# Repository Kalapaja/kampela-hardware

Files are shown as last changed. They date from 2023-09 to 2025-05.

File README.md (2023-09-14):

# Kampela

## Reasonably secure hardware signer for the [Polkadot](https://polkadot.network) ecosystem

### Hardware design schematics and supplementary files

##### Note on repo history

This repo has been extracted from https://github.com/Alzymologist/kampela in September 2023 as a part of the repo modularization effort.

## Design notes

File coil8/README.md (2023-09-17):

# Kampela coil PCB

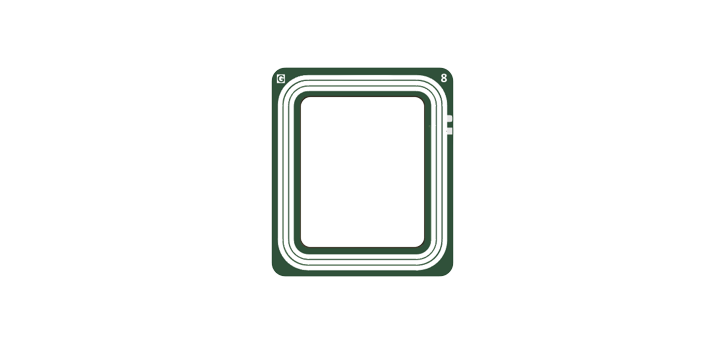
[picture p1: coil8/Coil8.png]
Kampela coil PCB


We are using a separate coil PCB to put it as much closer to the smartphone antenna as possible. 
8 turns design shows better energy performance for harvesting energy for Kampela.

The coil PCB connects with the main PCB with 2 short copper wires.

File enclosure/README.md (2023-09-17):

# Kampela Enclosure G2

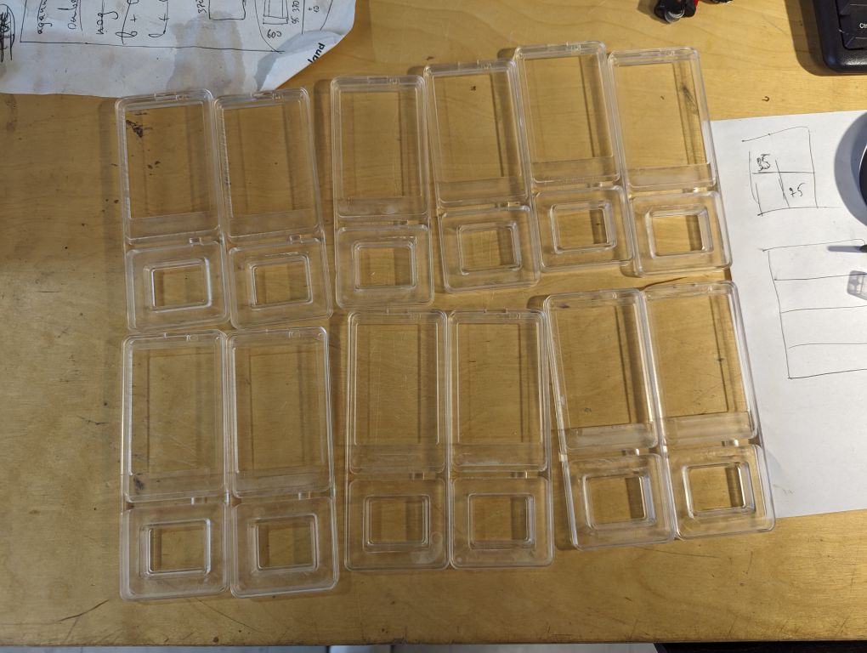
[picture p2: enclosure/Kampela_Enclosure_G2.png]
Kampela Enclosure G2


For the Kampela G2 revision, we use a rigid transparent acrylic enclosure made on a CNC machine from an 8mm transparent acrylic sheet and pour it with 2 components of transparent polyurethane after full assembly and testing.

For devkits (green PCBs and full transparent) there is an 8pin connector on the bottom of the device to connect it to the Pilkki flash tool.

Under the screen, there is a place for an NFC tag working in pair with Kampela.

Before placing the PCBs and the screen - you should put a flexible glue contour to all holes contours and glue all the components during assembly. This glue prevents polyurethane pouring from leaking on the screen and inside the devkit connector.

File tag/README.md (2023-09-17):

# Kampela NFC Tag

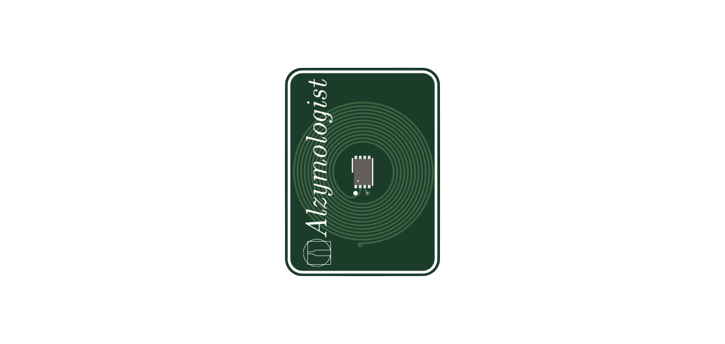
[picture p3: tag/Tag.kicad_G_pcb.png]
Kampela NFC Tag


Kampela NFC Tag is used as a Kampela companion for direct NFC communication with a phone, while Kampela remains be completely passive device minimizing the transmittion of any RF signal even not changing the NFC receiver quality factor to communicate with a user smartphone.

A nice bonus of this approach is that the tag is the second security factor - Kampela doesn't work without the correct tag to prevent simple attacks.

Kampela NFC Tag is also poured into a transparent enclosure to protect it from the harsh environment and silent modification.

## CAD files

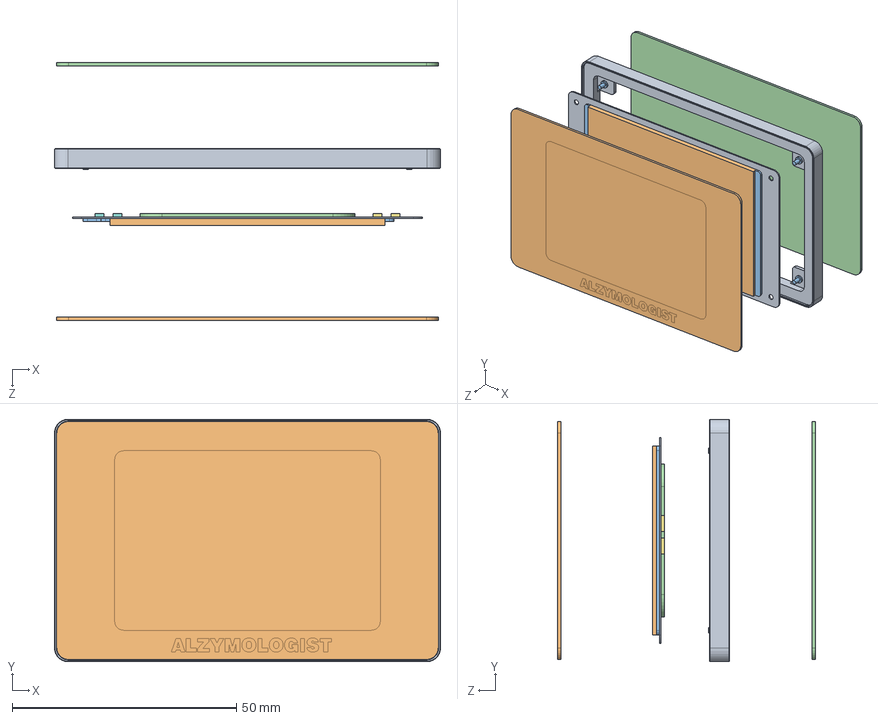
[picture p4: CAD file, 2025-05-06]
enclosure/new_layout/Assembly1.SLDASM
86.0 x 54.0 x 57.4 mm
плата
экран
обвязка экрана
нфц
детали 1
детали 2
детали 3
детали 4
Стекло front
Крепеж
Стекло

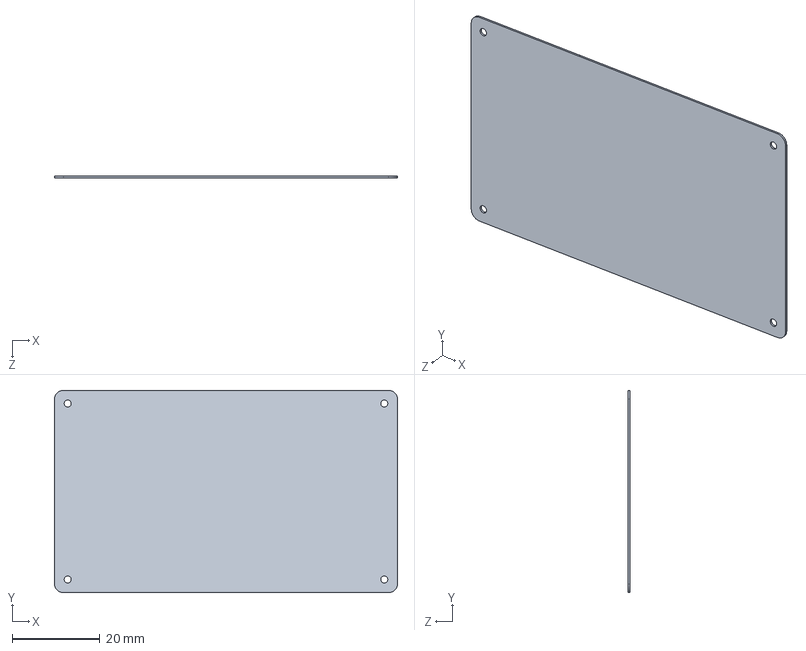
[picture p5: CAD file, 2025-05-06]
enclosure/new_layout/Board.SLDPRT
78.0 x 46.0 x 0.4 mm

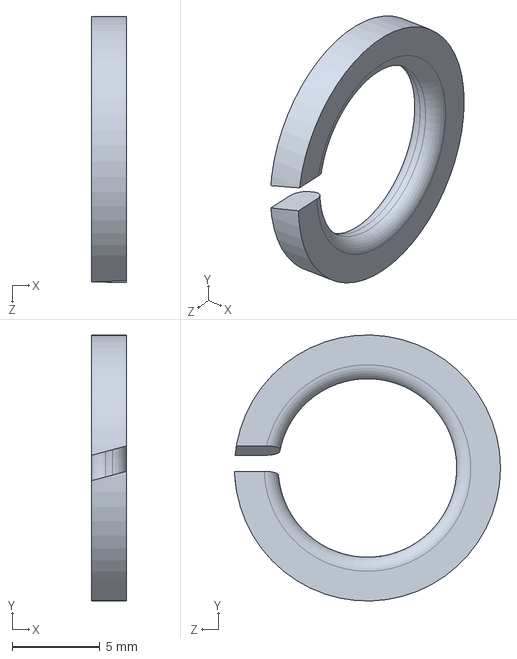
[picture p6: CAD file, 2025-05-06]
enclosure/new_layout/mass_production/PS-10.2x2.sldprt
2.00 x 15.2 x 15.2 mm

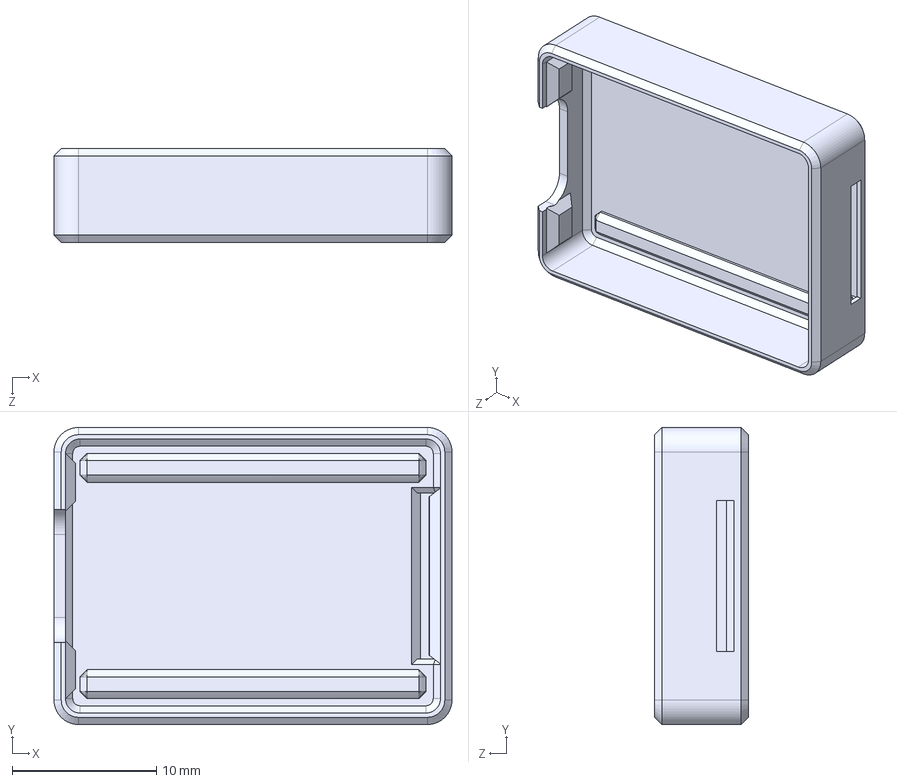
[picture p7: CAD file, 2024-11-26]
enclosure/Prog2Bot.STEP
27.6 x 20.6 x 6.50 mm

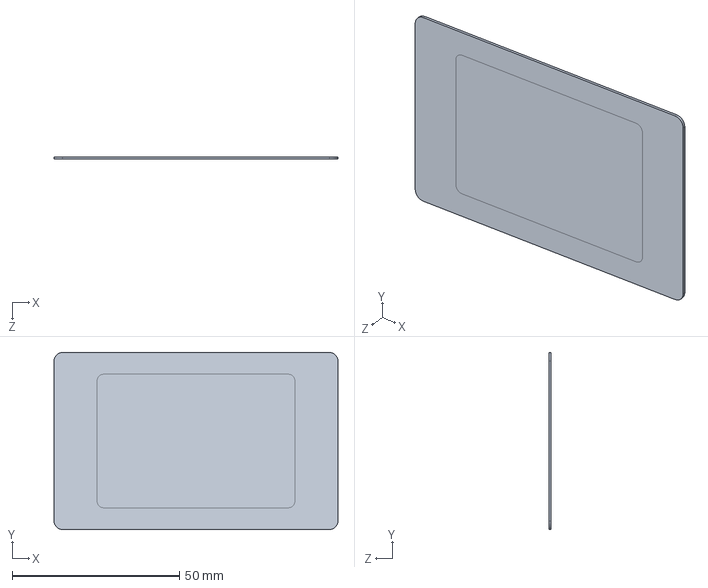
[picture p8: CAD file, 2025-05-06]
enclosure/new_layout/Glass front.SLDPRT
85.0 x 53.0 x 0.701 mm

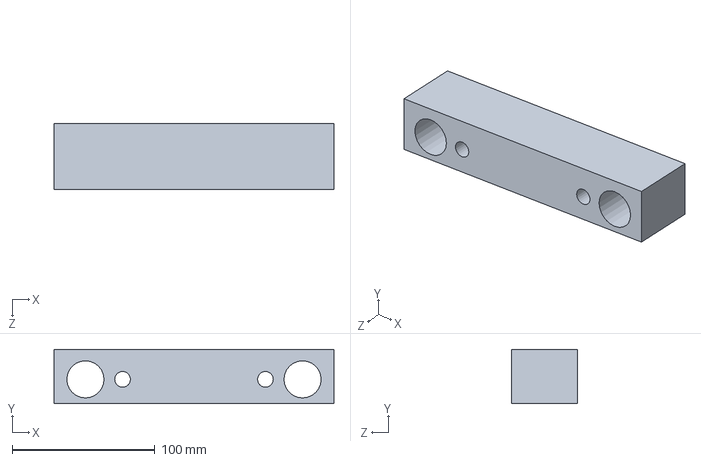
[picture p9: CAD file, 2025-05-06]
enclosure/new_layout/mass_production/PK 05-196x196x46_1730.sldprt
196.0 x 38.0 x 46.0 mm

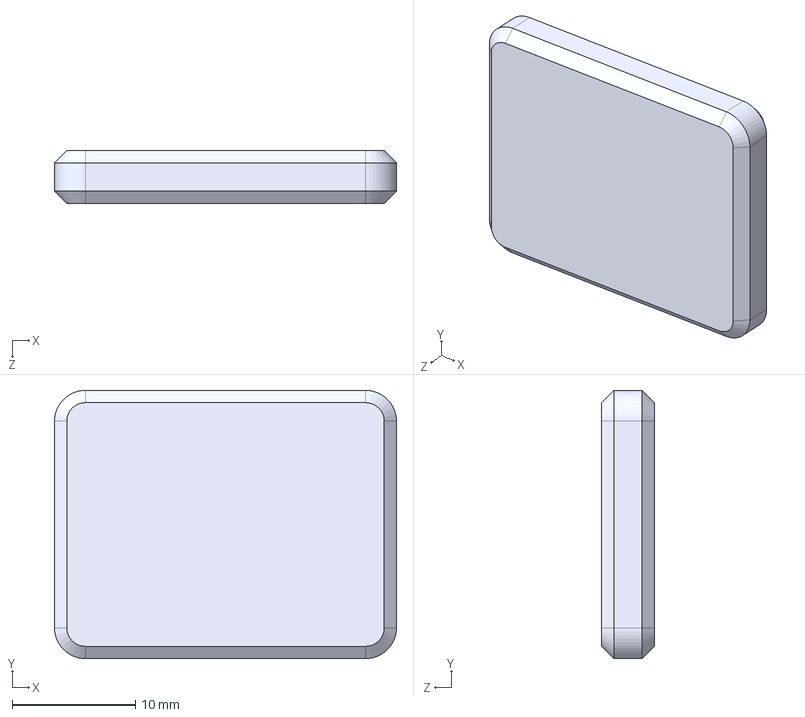
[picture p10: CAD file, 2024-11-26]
enclosure/TAG5.STEP
27.8 x 21.8 x 4.30 mm

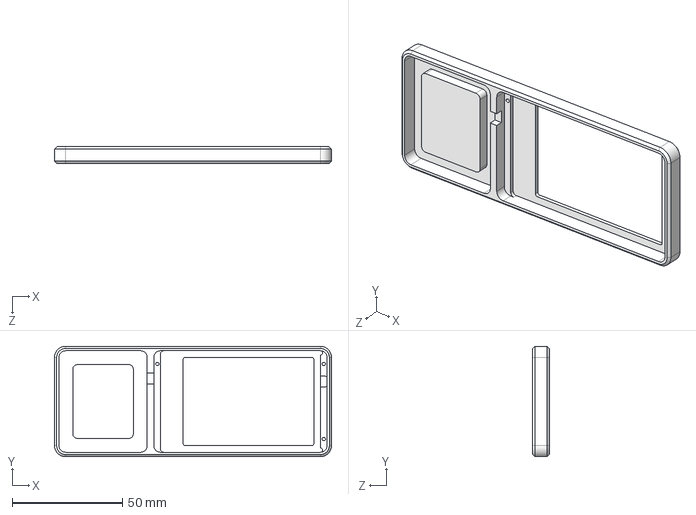
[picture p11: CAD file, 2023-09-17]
enclosure/Kampela_Enclosure.STEP
125.5 x 50.0 x 7.50 mm

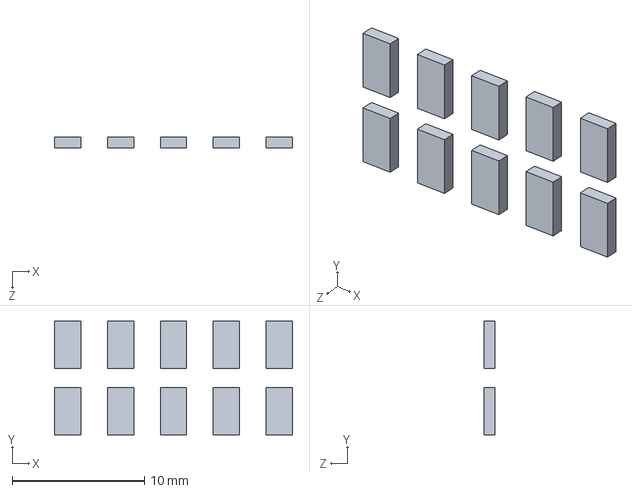
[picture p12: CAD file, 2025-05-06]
enclosure/new_layout/Details 1.SLDPRT
18.0 x 8.60 x 0.8 mm

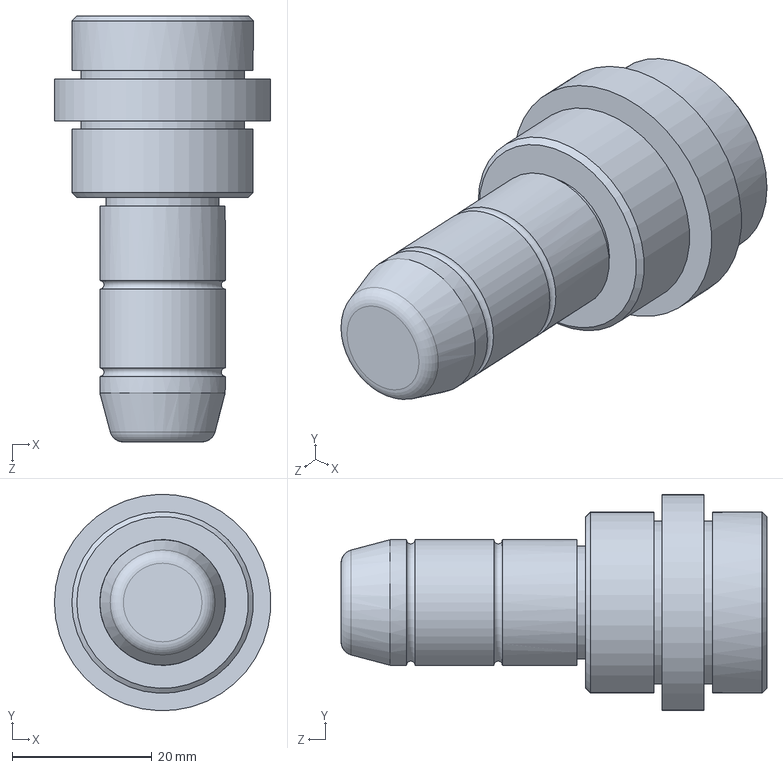
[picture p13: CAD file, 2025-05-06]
enclosure/new_layout/mass_production/SLE-18017035.sldprt
31.0 x 31.0 x 61.0 mm

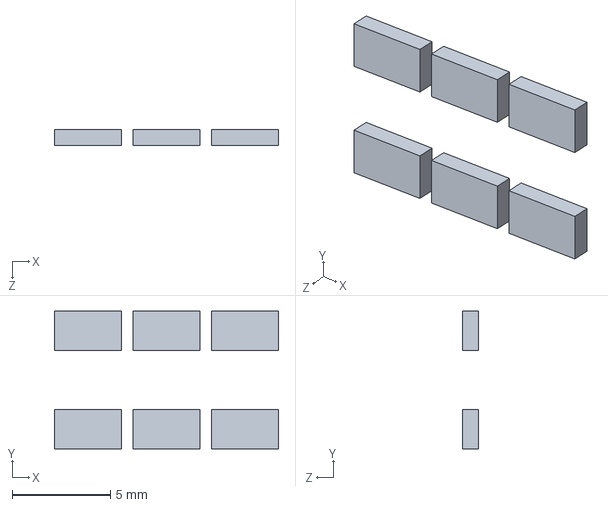
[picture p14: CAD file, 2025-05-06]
enclosure/new_layout/Details 2.SLDPRT
11.4 x 7.00 x 0.8 mm

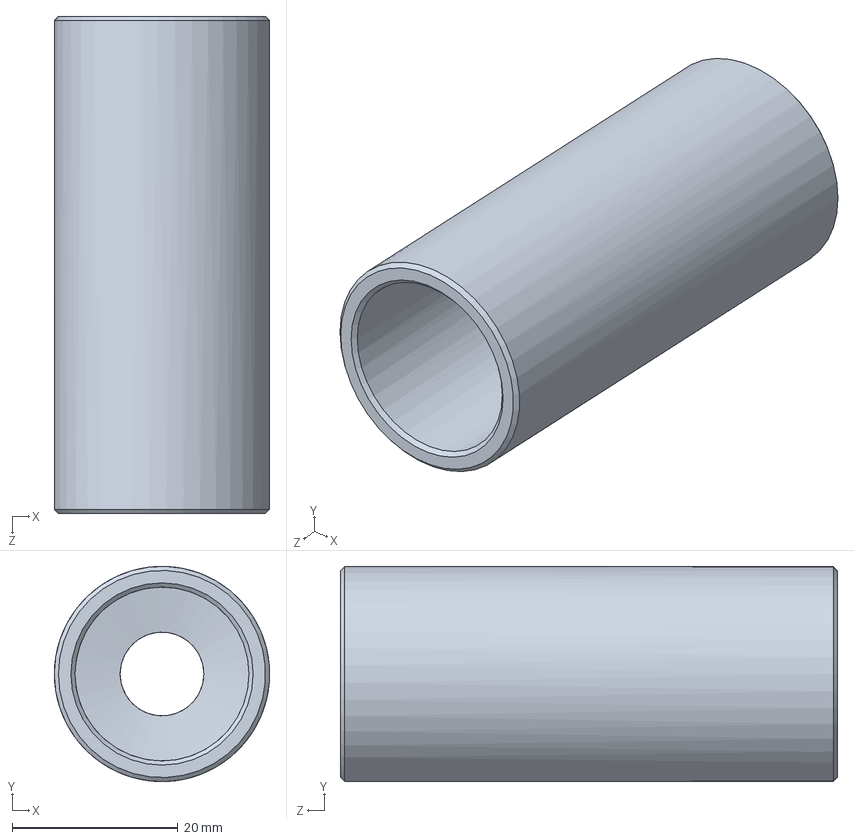
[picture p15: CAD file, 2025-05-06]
enclosure/new_layout/mass_production/TUE-26060.sldprt
26.0 x 26.0 x 60.0 mm

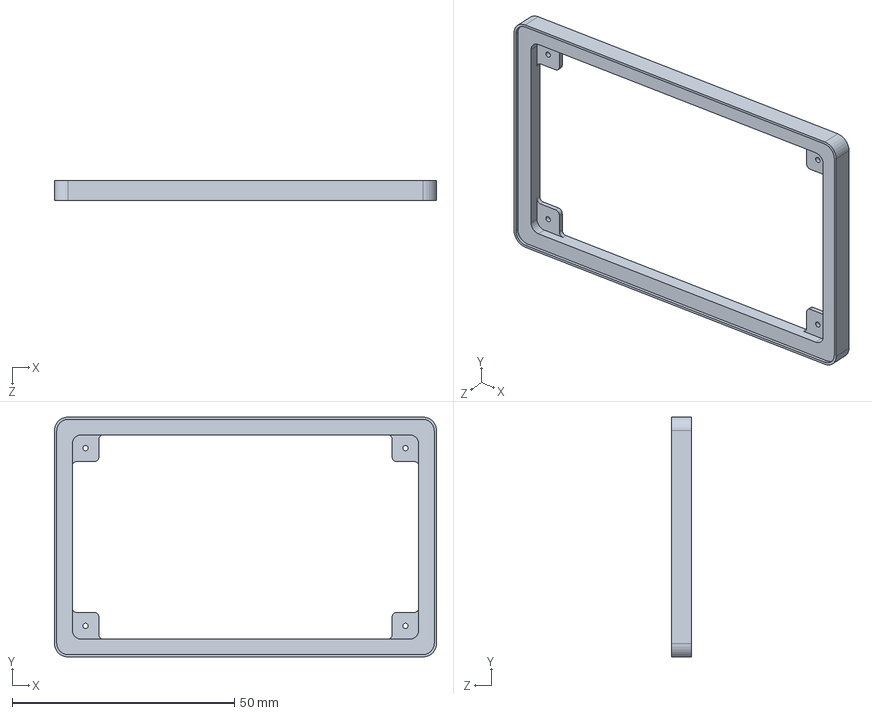
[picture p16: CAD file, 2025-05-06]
enclosure/new_layout/Body.SLDPRT
86.0 x 54.0 x 4.40 mm

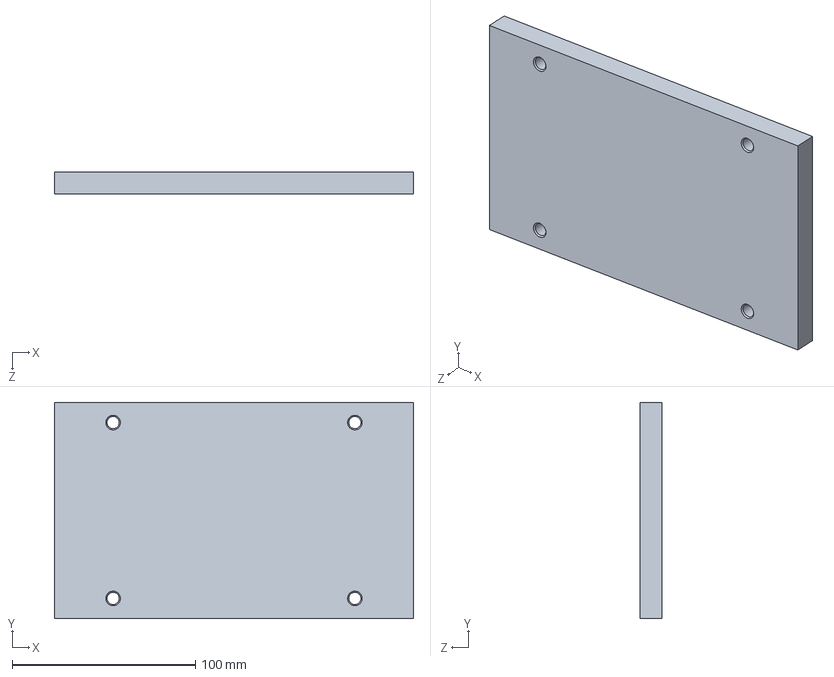
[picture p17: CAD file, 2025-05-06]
enclosure/new_layout/mass_production/PK 06-196x196x12_1730.sldprt
196.0 x 118.0 x 12.0 mm

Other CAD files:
enclosure/new_layout/mass_production/$$FCPK_196x196_PK_PK01_22_1_1730_PK03_17_1_1730_PK03_17_1_1730_NO.sldasm
enclosure/new_layout/mass_production/PK 11-196x196x22_1730.sldprt
enclosure/new_layout/Screen.SLDPRT
enclosure/new_layout/Details 3.SLDPRT
enclosure/new_layout/Details 4.SLDPRT
enclosure/new_layout/Glass.SLDPRT
enclosure/new_layout/Mounting.SLDPRT
enclosure/new_layout/NFC.SLDPRT
enclosure/new_layout/Screen wiring.SLDPRT
enclosure/new_layout/mass_production/FCPK_196x196_PK_PK01_22_1_1730_PK03_17_1_1730_PK03_17_1_1730_NO.sldasm
enclosure/new_layout/mass_production/PK 01-196x196x22_1730.sldprt
enclosure/new_layout/mass_production/PK 03-196x196x17_1730.sldprt
enclosure/new_layout/mass_production/PK 04-196x196x17_1730.sldprt
enclosure/new_layout/mass_production/PK 07-196x196x17_1730.sldprt
enclosure/new_layout/mass_production/PO-1803.sldprt
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

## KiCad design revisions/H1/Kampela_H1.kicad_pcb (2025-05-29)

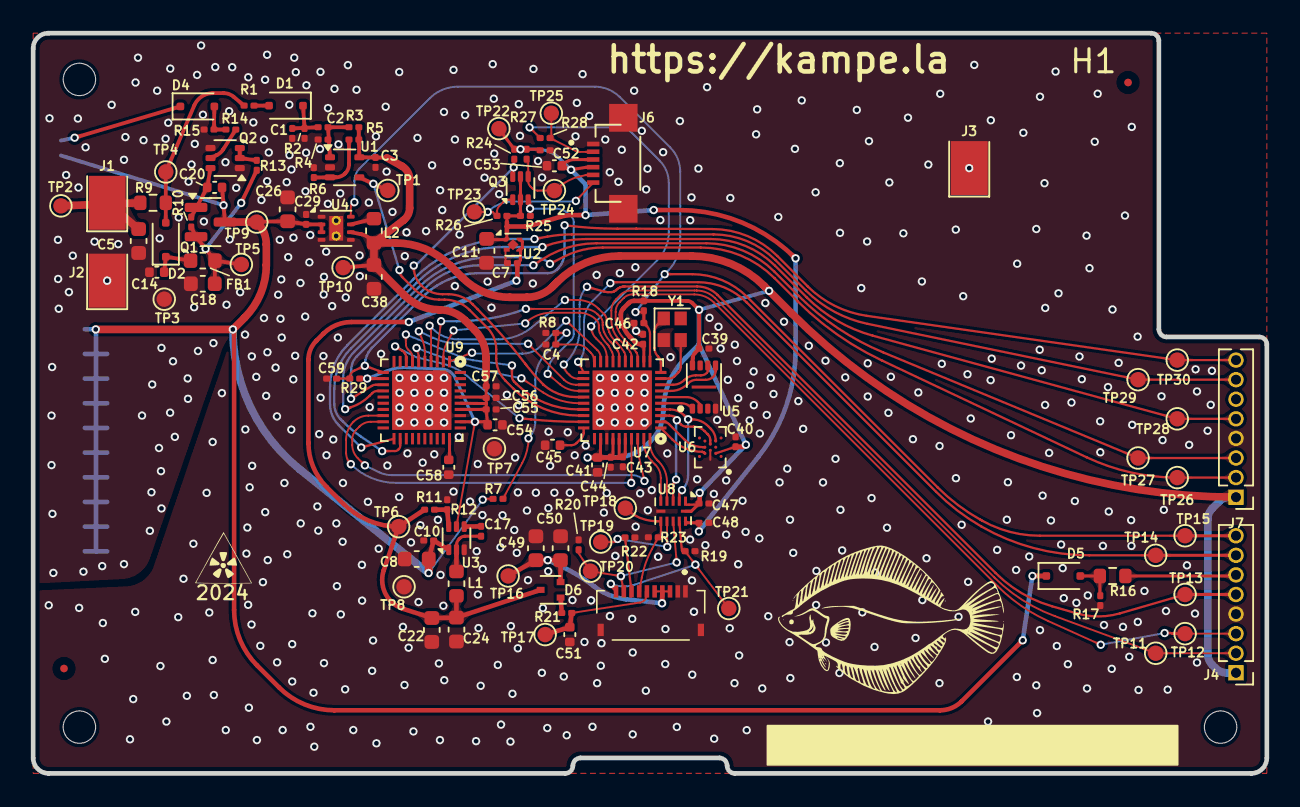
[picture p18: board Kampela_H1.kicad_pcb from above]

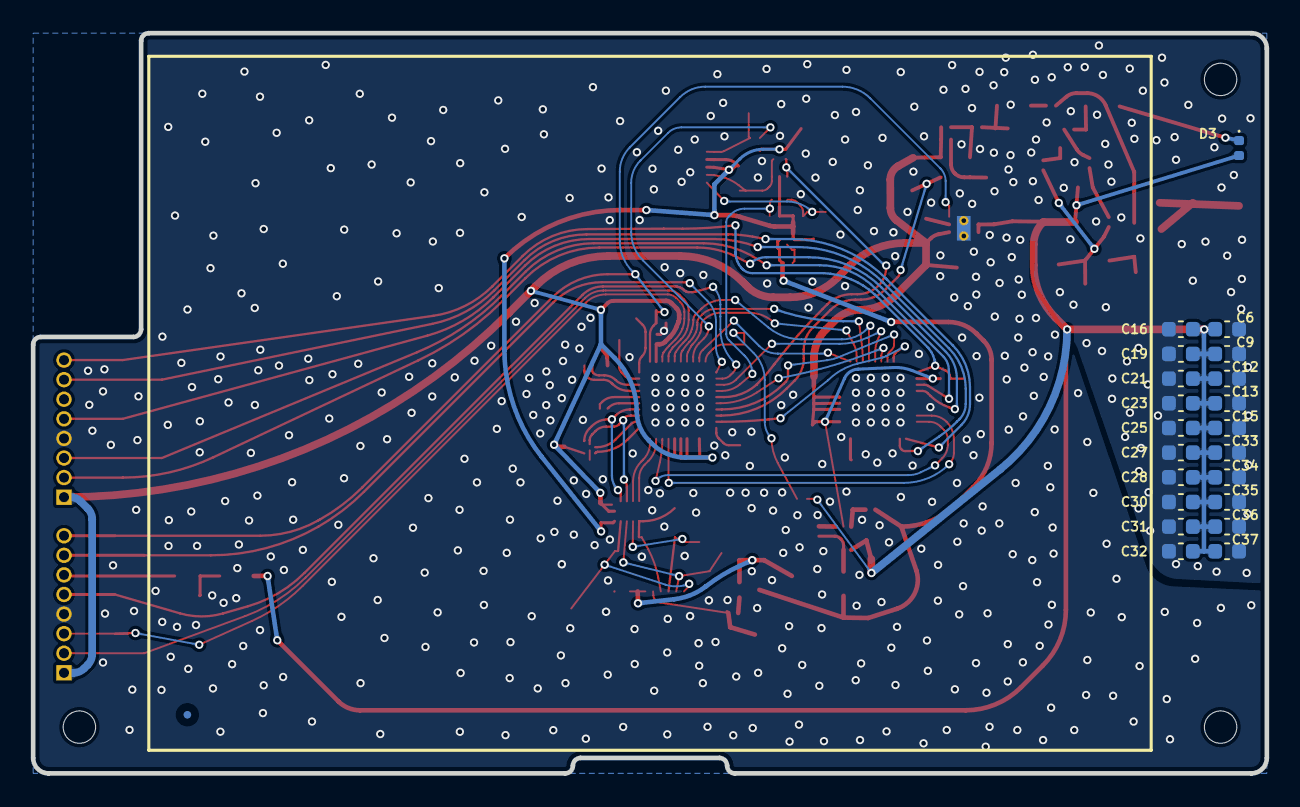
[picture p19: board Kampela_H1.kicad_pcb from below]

Board: 2 copper layers, 80.0 x 48.0 mm, 153 parts (22 on the bottom side), 73 nets.

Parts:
C1, C2: 100p; C_0201_0603Metric
C3, C4, C7, C10, C17, C29, C39, C40, C42, C43, C44, C46, C47, C48, C52, C55, C56, C57, C59: 0.1; C_0201_0603Metric
C5: 15p; C_0603_1608Metric
C6, C9, C12, C13, C15, C16, C19, C21, C23, C25, C27, C28, C30, C31, C32, C33, C34, C35, C36, C37: 22x16; C_0603_1608Metric
C8, C18, C26: 10x25; C_0603_1608Metric
C11, C22, C24, C38, C49, C50: 22x6.3; C_0603_1608Metric
C14, C20: 1x50; C_0402_1005Metric
C41, C45, C51, C53, C54, C58: 1x6.3; C_0402_1005Metric
D1, D5: BAT54WS; D_SOD-323F
D2: BAS70WS; D_SOD-323F
D3: RED; LED_0402_1005Metric
D4: D3Z13BF-7; D_SOD-323F
D6: BAT54AW; SOT-523
FB1: BLM18KG102SN1D; L_0603_1608Metric
FID1, FID2, FID4: Fiducial; Fiducial_0.5mm_Mask1.5mm
H1, H2, H3: MountingHole; MountingHole_2.1mm
J1, J2, J3: E_ANT; TestPoint_Pad_2.4x3.5mm
J4, J7: Conn_01x08; PinHeader_1x08_P1.27mm_Vertical
J5: FPC 10 TE1-2328702-0; TE_123287020
J6: TOUCH; HRS_FH34SRJ-6S-0.5SH(50)
L1, L2: 4.7uH; L_0603_1608Metric
Q1: NTR5105PT1G; SOT-23
Q2: BC846BS; SOT-363_SC-70-6
Q3: SSM6N35AFE; SOT-563
R1, R12, R15, R17, R18, R24, R25, R26, R27, R28, R29: 10K; R_0201_0603Metric
R2, R5, R11: 52.3K; R_0201_0603Metric
R3, R4, R10, R13, R19, R20, R22, R23: 100K; R_0201_0603Metric
R6, R14: 46.4K; R_0201_0603Metric
R7, R21: 1M; R_0201_0603Metric
R8: 150K; R_0201_0603Metric
R9, R16: 2.2; R_0603_1608Metric
TP1, TP2, TP3, TP4, TP5, TP6, TP7, TP8, TP9, TP10, TP11, TP12, TP13, TP14, TP15, TP16, TP17, TP18, TP19, TP20, TP21, TP22, TP23, TP24, TP25, TP26, TP27, TP28, TP29, TP30: TestPoint; TestPoint_Pad_D1.0mm
U1: LMV7271; SOT-353_SC-70-5
U2: NCP170AMX180TBG; OnSemi_XDFN4-1EP_1.0x1.0mm_EP0.52x0.52mm
U3: AP62250Z6; SOT-563
U4: TPS62171DSG; WSON-8-1EP_2x2mm_P0.5mm_EP0.9x1.6mm_ThermalVias
U5: APS6404L-SQN; SON-8-1EP_3x2mm_P0.5mm_EP1.4x1.6mm
U6: AT25XE321D-UUN-T; WLCSP 12-ball 3 x 2 x 3 Array
U7, U9: EFM32PG23B200F512IM40; QFN-40_EP_5x5_Pitch0.4mm
U8: TXU0104PW; Texas_R-PUQFN-N12
Y1: 39MHz; Crystal_SMD_2016-4Pin_2.0x1.6mm

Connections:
+1V8: C3.1, C38.1, C39.2, C40.2, C41.1, C42.2, C43.2, C44.2, C47.1, C54.1, C55.2, C56.2, C57.2, J4.1, J7.1, L2.2, R3.2, R5.2, R18.2, R29.2, TP10.1, U1.5 (V+), U3.5 (EN), U4.6 (VOS), U5.8 (VCC), U6.B2 (VCC), U7.12 (DVDD), U7.32 (VREGVDD), U7.34 (DVDD), U7.35 (AVDD), U7.36 (IOVDD), U8.1 (VCCA), U8.12 (OE), U9.12 (DVDD), U9.32 (VREGVDD), U9.34 (DVDD), U9.35 (AVDD), U9.36 (IOVDD)
+3V0: C11.2, C48.1, C52.2, C53.1, J6.3, J6.4, Q3.2 (G), Q3.5 (G), R24.2, R25.2, R26.2, R27.2, TP22.1, U2.1 (OUT), U8.11 (VCCB)
+5V: C7.2, C22.1, C24.2, D6.3, L1.2, R11.2, TP6.1, U2.3 (EN), U2.4 (IN)
/Display/CS: U7.40 (PD00), U8.4 (A3)
/Display/EXTIN: U7.39 (PD01), U8.5 (A4)
/Display/H_CS: J5.8, R22.2, TP19.1, U8.8 (B3)
/Display/H_EXTIN: J5.7, R23.2, TP18.1, U8.7 (B4)
/Display/H_SCK: J5.10, R19.2, TP21.1, U8.10 (B1)
/Display/H_SDI: J5.9, R20.2, TP20.1, U8.9 (B2)
/Display/INT: R28.1, U7.18 (PB01)
/Display/SCL: Q3.3 (D), R25.1, U7.24 (PA04)
/Display/SDA: Q3.6 (D), R24.1, U7.25 (PA05)
/Display/T_INT: J6.2, R28.2, TP25.1
/Display/T_SCL: J6.5, Q3.4 (S), R27.1, TP24.1
/Display/T_SDA: J6.6, Q3.1 (S), R26.1, TP23.1
/MCU SEC/ALEPH: U7.19 (PB00), U9.1 (PC00)
/MCU SEC/BET: U7.17 (PB02), U9.2 (PC01)
/MCU SEC/DALET: U7.15 (PB04), U9.4 (PC03)
/MCU SEC/DATA: TP1.1, U1.4, U7.28 (PA08)
/MCU SEC/E_MISO: U6.D4 (IO1/SO), U7.2 (PC01)
/MCU SEC/E_MOSI: U6.E3 (SI/IO0), U7.3 (PC02), U8.3 (A2)
/MCU SEC/E_SCK: U6.F2 (SCK), U7.4 (PC03), U8.2 (A1)
/MCU SEC/FLASH_CS: U6.B4 (~CS), U7.1 (PC00)
/MCU SEC/GIMEL: U7.16 (PB03), U9.3 (PC02)
/MCU SEC/HE: U7.23 (PA03), U9.5 (PC04)
/MCU SEC/HET: U7.29 (PA09), U9.8 (PC07)
/MCU SEC/P_GOOD: C46.2, J4.8, R18.1, TP15.1, U4.8 (PG), U7.11 (~RESET)
/MCU SEC/P_IN: J4.6, R16.1
/MCU SEC/RAM_CS: U5.1 (~CE), U7.5 (PC04)
/MCU SEC/RX: J4.2, TP11.1, U7.14 (PB05)
/MCU SEC/R_MISO: U5.2 (SO/SIO), U7.6 (PC05)
/MCU SEC/R_MOSI: U5.5 (SI/SIO), U7.7 (PC06)
/MCU SEC/R_SCK: U5.6 (SCLK), U7.8 (PC07)
/MCU SEC/SWDCK: J4.7, TP14.1, U7.21 (PA01)
/MCU SEC/SWDIO: J4.5, TP13.1, U7.22 (PA02)
/MCU SEC/TET: U7.38 (PD02), U9.19 (PB00)
/MCU SEC/TX: J4.3, TP12.1, U7.13 (PB06)
/MCU SEC/VAV: U7.26 (PA06), U9.6 (PC05)
/MCU SEC/V_CHK: C4.2, R7.1, R8.2, U7.20 (PA00)
/MCU SEC/YOD: U7.37 (PD03), U9.18 (PB01)
/MCU SEC/ZAYIN: U7.27 (PA07), U9.7 (PC06)
/MCU UI/P_GOOD: C59.2, J7.8, R29.1, TP30.1, U9.11 (~RESET)
/MCU UI/RX: J7.2, TP26.1, U9.14 (PB05)
/MCU UI/SWDCK: J7.7, TP29.1, U9.21 (PA01)
/MCU UI/SWDIO: J7.5, TP28.1, U9.22 (PA02)
/MCU UI/TX: J7.3, TP27.1, U9.13 (PB06)
/Power/OUT_DT: D2.2 (A), R1.1, R9.2, TP4.1
GND: C1.1, C3.2, C4.1, C5.2, C6.2, C7.1, C8.2, C9.2, C10.1, C11.1, C12.2, C13.2, C14.2, C15.2, C16.2, C18.2, C19.2, C21.2, C22.2, C23.2, C24.1, C25.2, C26.2, C27.2, C28.2, C29.1, C30.2, C31.2, C32.2, C33.2, C34.2, C35.2, C36.2, C37.2, C38.2, C39.1, C40.1, C41.2, C42.1, C43.1, C44.1, C45.2, C46.1, C47.2, C48.2, C49.1, C50.1, C51.2, C52.1, C53.2, C54.2, C55.1, C56.1, C57.1, C58.2, C59.1, J2.1, J3.1, J4.4, J5.1, J5.2, J5.MP1, J5.MP2, J6.1, J6.S2 (S), J7.4, Q2.1 (E1), Q2.4 (E2), R2.1, R4.1, R6.1, R8.1, R12.1, R15.1, R17.1, R19.1, R20.1, R22.1, R23.1, TP3.1, TP7.1, TP8.1, U1.2 (V-), U2.2 (GND), U2.5 (GND), U3.3 (GND), U4.1 (PGND), U4.4 (AGND), U4.5 (FB), U4.9 (PAD), U5.4 (VSS), U6.C3 (GND), U7.33 (VREGVSS), U7.41 (VSS), U8.6 (GND), U9.33 (VREGVSS), U9.41 (VSS), Y1.2
HV: C6.1, C8.1, C9.1, C10.2, C12.1, C13.1, C15.1, C16.1, C19.1, C20.2, C21.1, C23.1, C25.1, C26.1, C27.1, C28.1, C29.2, C30.1, C31.1, C32.1, C33.1, C34.1, C35.1, C36.1, C37.1, D3.2 (A), D5.1 (K), Q1.3 (D), R7.2, TP9.1, U3.1 (VIN), U4.2 (VIN), U4.3 (EN)
unnamed: C49.2, C50.2, D6.2, J5.3, J5.4, J5.5, TP16.1
unnamed: C51.1, J5.6, R21.1, TP17.1
unnamed: D1.2 (A), R1.2
unnamed: C1.2, C2.2, D1.1 (K), R2.2
unnamed: C14.1, D2.1 (K), FB1.2
unnamed: D3.1 (K), D4.1 (K)
unnamed: D4.2 (A), R14.1, R15.2
unnamed: D5.2 (A), R16.2, R17.2
unnamed: D6.1, R21.2
unnamed: C5.1, J1.1, R9.1, TP2.1
unnamed: C20.1, Q1.1 (G), Q2.6 (C1), R10.2
unnamed: C18.1, FB1.1, Q1.2 (S), R10.1, R13.2, TP5.1
unnamed: Q2.2 (B1), Q2.3 (C2), R13.1
unnamed: Q2.5 (B2), R14.2
unnamed: C2.1, R3.1, R4.2, U1.1 (+)
unnamed: R5.1, R6.2, U1.3 (-)
unnamed: C17.1, U3.4 (BST)
unnamed: R11.1, R12.2, U3.6 (FB)
unnamed: C17.2, L1.1, U3.2 (SW)
unnamed: L2.1, U4.7 (SW)
unnamed: C45.1, U7.30 (CAP)
unnamed: U7.9 (HFXTAL_I), Y1.3
unnamed: U7.10 (HFXTAL_O), Y1.1
unnamed: C58.1, U9.30 (CAP)

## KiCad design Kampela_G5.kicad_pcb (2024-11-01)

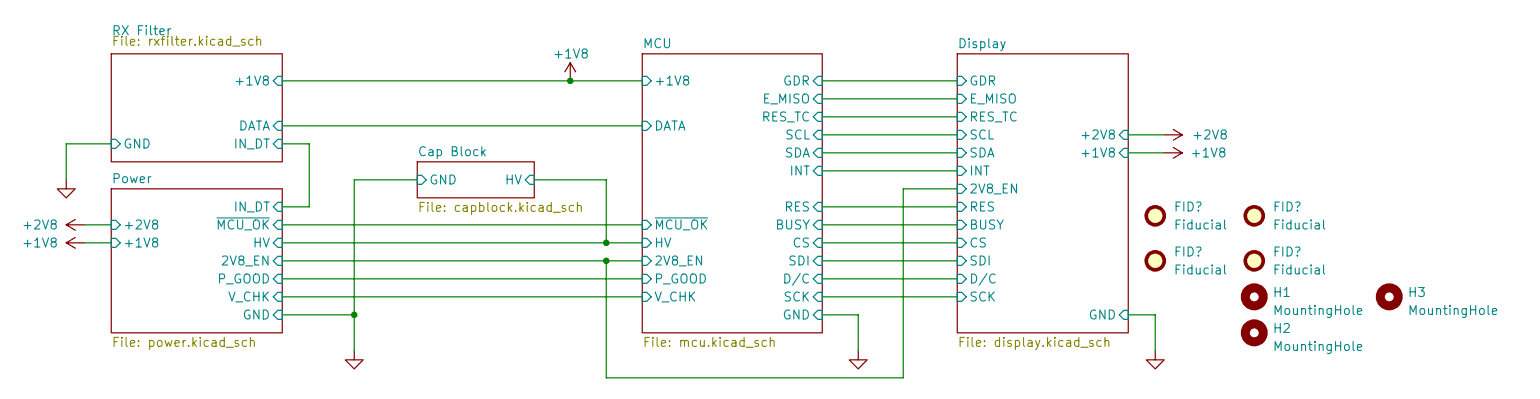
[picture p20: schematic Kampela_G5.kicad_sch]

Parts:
FID1, FID2, FID3, FID4: Fiducial; Fiducial_0.5mm_Mask1.5mm
H1, H2, H3: MountingHole; MountingHole_2.1mm

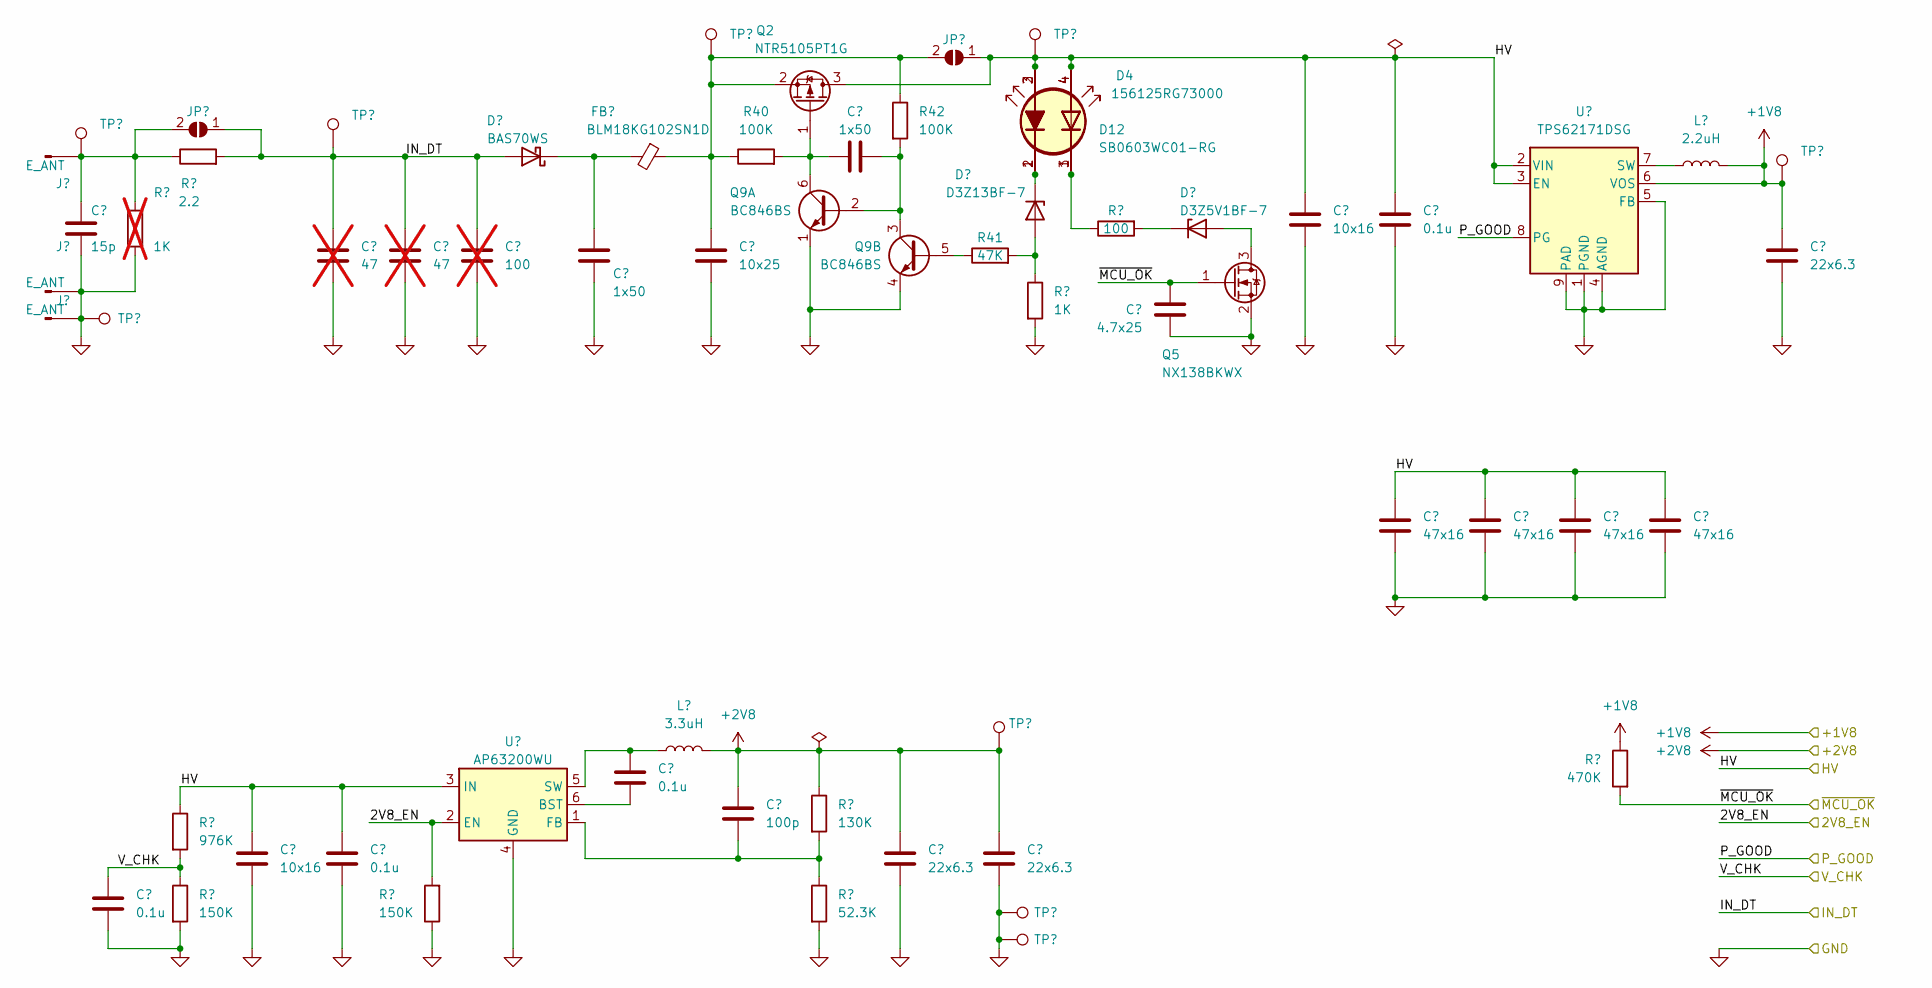
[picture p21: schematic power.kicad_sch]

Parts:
C9: 15p; C_0603_1608Metric
C12, C14: 47; C_0603_1608Metric; not fitted
C16: 100; C_0603_1608Metric; not fitted
C20, C23, C25, C26: 0.1u; C_0402_1005Metric
C21: 10x25; C_0603_1608Metric
C22, C24: 10x16; C_0603_1608Metric
C27: 100p; C_0402_1005Metric
C28: 4.7x25; C_0603_1608Metric
C29, C30, C31: 22x6.3; C_0603_1608Metric
C64, C72, C73, C80: 47x16; C_1210_3225Metric
C86, C87: 1x50; C_0402_1005Metric
D4: 156125RG73000; SMD4_WL-SBRW-1205_REV-MOUNT_WRE
D5: D3Z13BF-7; D_SOD-323F
D6: BAS70WS; D_SOD-323F
D8: D3Z5V1BF-7; D_SOD-323F
D12: SB0603WC01-RG; LED_DUAL_0603
FB2: BLM18KG102SN1D; L_0603_1608Metric
J1, J2, J8: E_ANT; TestPoint_Pad_2.4x3.5mm
JP1, JP11: SolderJumper_2_Open; SolderJumper_0.8.x1mm
L1: 3.3uH; L_Wuerth_MAPI-3015
L2: 2.2uH; L_Wuerth_MAPI-3015
Q2: NTR5105PT1G; SOT-23
Q5: NX138BKWX; SOT-323_SC-70
Q9: BC846BS; SOT-363_SC-70-6
R9: 1K; R_0603_1608Metric; not fitted
R10: 2.2; R_0603_1608Metric
R11: 976K; R_0402_1005Metric
R12, R14: 150K; R_0402_1005Metric
R13: 1K; R_0402_1005Metric
R15: 130K; R_0402_1005Metric
R16: 52.3K; R_0402_1005Metric
R30: 100; R_0402_1005Metric
R31: 470K; R_0402_1005Metric
R40, R42: 100K; R_0402_1005Metric
R41: 47K; R_0402_1005Metric
TP1, TP2, TP3, TP5, TP6, TP21, TP22, TP26, TP27: TestPoint; TestPoint_Pad_D1.0mm
U2: AP63200WU; TSOT-23-6
U3: TPS62171DSG; WSON-8-1EP_2x2mm_P0.5mm_EP0.9x1.6mm_ThermalVias

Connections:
+1V8: C30.2, L2.2, R31.1, TP2.1, U3.6 (VOS); also elsewhere on the board
+2V8: C27.1, C29.2, C31.2, L1.2, R15.1, TP3.1; also elsewhere on the board
/Display/2V8_EN: R14.2, U2.2 (EN); also elsewhere on the board
/MCU/P_GOOD: U3.8 (PG); also elsewhere on the board
/MCU/V_CHK: C20.1, R11.2, R12.1; also elsewhere on the board
/MCU/~MCU_OK: C28.2, Q5.1 (G), R31.2; also elsewhere on the board
/Power/IN_DT: C12.1, C14.1, C16.1, D6.2 (A), JP1.1 (A), R10.2, TP1.1; also elsewhere on the board
GND: C9.2, C12.2, C14.2, C16.2, C20.2, C21.1, C22.1, C23.2, C24.1, C25.2, C28.1, C29.1, C30.1, C31.1, C64.1, C72.1, C73.1, C80.1, C86.2, J2.1, J8.1, Q5.2 (S), Q9.1 (E1), Q9.4 (E2), R9.1, R12.2, R13.2, R14.1, R16.2, TP21.1, TP22.1, TP27.1, U2.4 (GND), U3.1 (PGND), U3.4 (AGND), U3.5 (FB), U3.9 (PAD); also elsewhere on the board
unnamed: D5.2 (A), R13.1, R41.2
unnamed: C86.1, D6.1 (K), FB2.2
unnamed: D8.2 (A), Q5.3 (D)
unnamed: D8.1 (K), R30.2
unnamed: D4.2 (K2), D5.1 (K), D12.1 (A1)
unnamed: D4.1 (K1), D12.3 (A2), R30.1
unnamed: C9.1, J1.1, JP1.2 (B), R9.2, R10.1, TP26.1
unnamed: C87.2, Q9.2 (B1), Q9.3 (C2), R42.2
unnamed: Q9.5 (B2), R41.1
unnamed: C26.2, U2.6 (BST)
unnamed: C27.2, R15.2, R16.1, U2.1 (FB)
unnamed: C26.1, L1.1, U2.5 (SW)
unnamed: L2.1, U3.7 (SW)

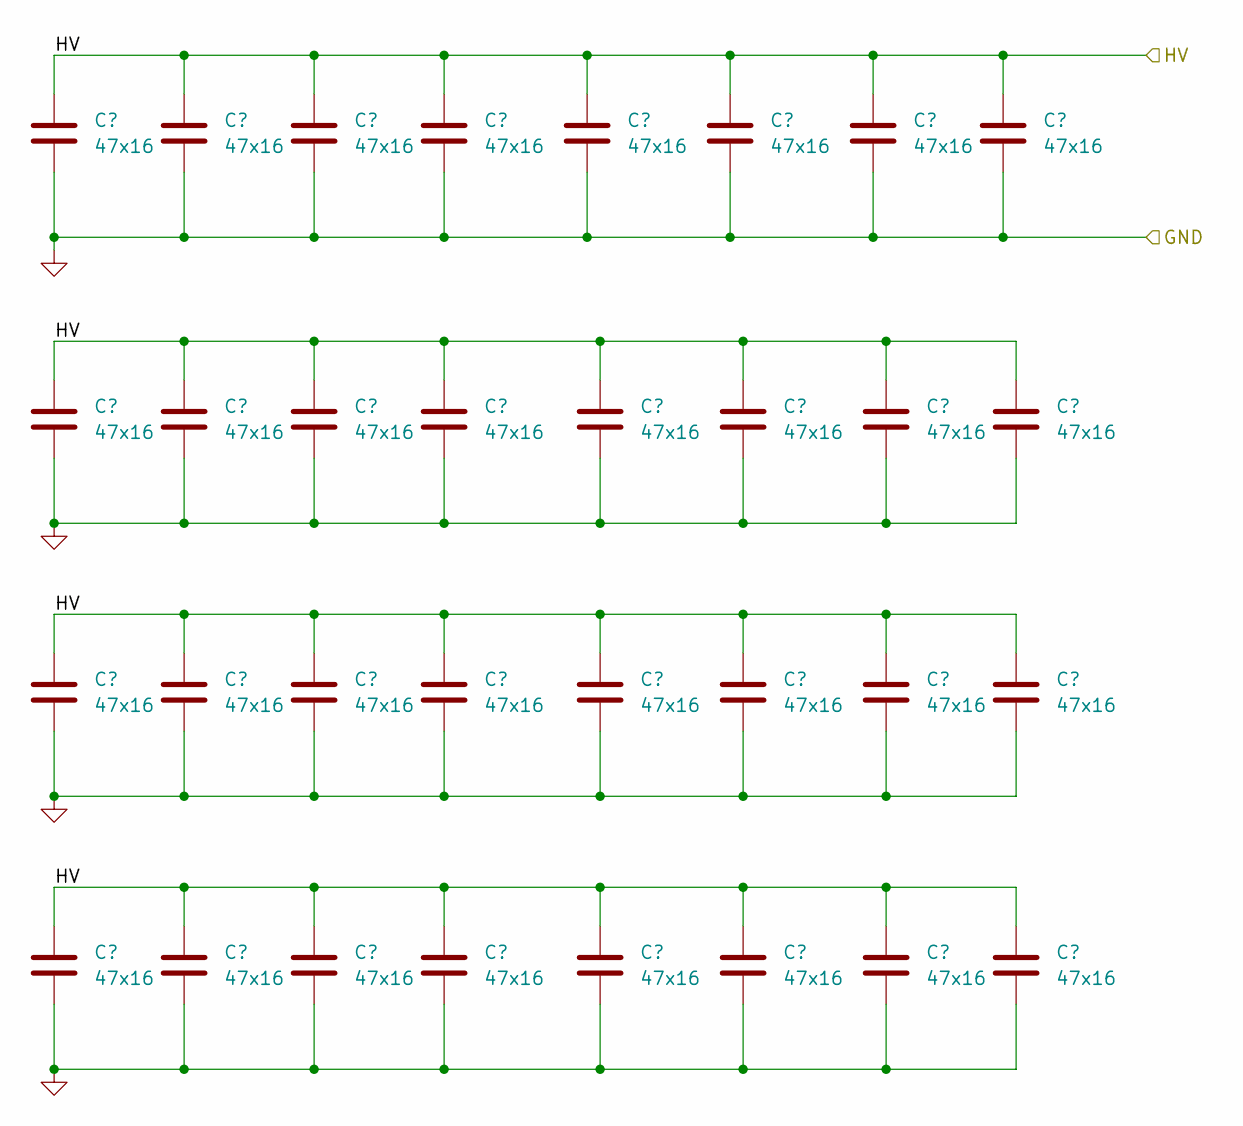
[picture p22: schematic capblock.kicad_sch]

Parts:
C6, C8, C10, C11, C13, C15, C17, C19, C58, C59, C60, C61, C62, C63, C65, C66, C67, C68, C69, C70, C71, C74, C75, C76, C77, C78, C79, C81, C82, C83, C84, C85: 47x16; C_1210_3225Metric

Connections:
GND: C6.1, C8.1, C10.1, C11.1, C13.1, C15.1, C17.1, C19.1, C58.1, C59.1, C60.1, C61.1, C62.1, C63.1, C65.1, C66.1, C67.1, C68.1, C69.1, C70.1, C71.1, C74.1, C75.1, C76.1, C77.1, C78.1, C79.1, C81.1, C82.1, C83.1, C84.1, C85.1; also elsewhere on the board

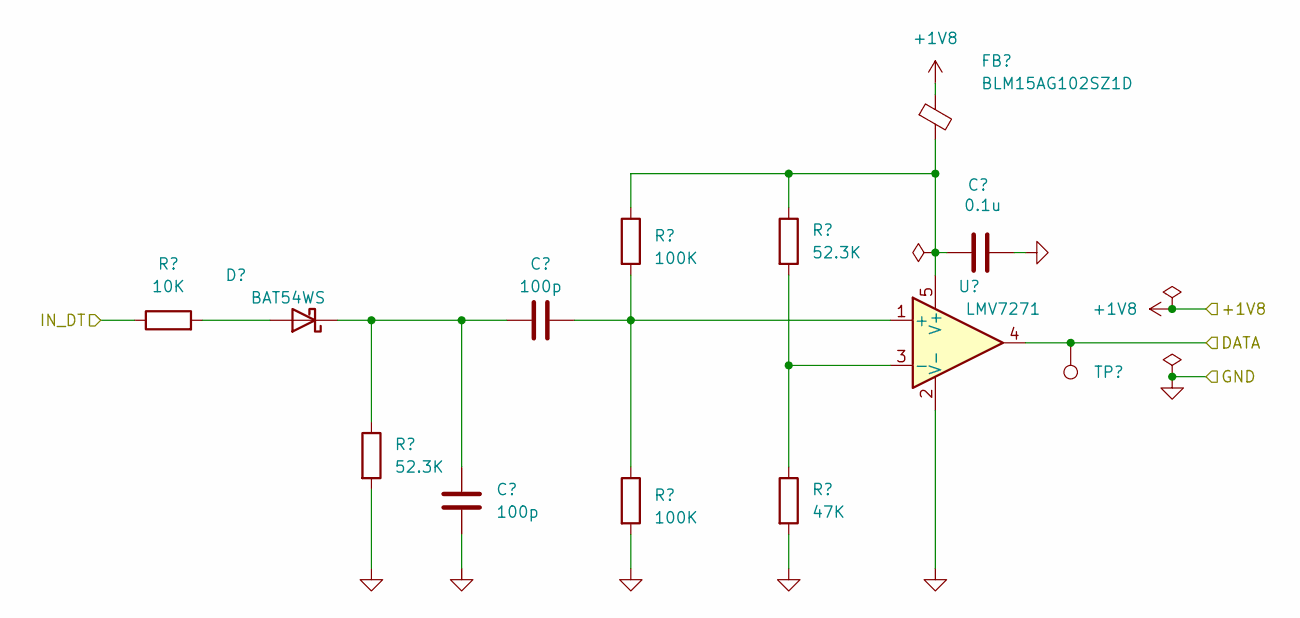
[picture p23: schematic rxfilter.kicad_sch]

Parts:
C2, C3: 100p; C_0402_1005Metric
C5: 0.1u; C_0402_1005Metric
D2: BAT54WS; D_SOD-323F
FB1: BLM15AG102SZ1D; L_0402_1005Metric
R1: 10K; R_0402_1005Metric
R2, R3: 52.3K; R_0402_1005Metric
R4: 47K; R_0402_1005Metric
R5, R7: 100K; R_0402_1005Metric
TP4: TestPoint; TestPoint_Pad_D1.0mm
U1: LMV7271; SOT-353_SC-70-5

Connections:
+1V8: FB1.1; also elsewhere on the board
/MCU/DATA: TP4.1, U1.4; also elsewhere on the board
/Power/IN_DT: R1.1; also elsewhere on the board
GND: C2.2, C5.1, R2.2, R4.2, R7.2, U1.2 (V-); also elsewhere on the board
unnamed: D2.2 (A), R1.2
unnamed: C2.1, C3.2, D2.1 (K), R2.1
unnamed: C3.1, R5.2, R7.1, U1.1 (+)
unnamed: R3.2, R4.1, U1.3 (-)
unnamed: C5.2, FB1.2, R3.1, R5.1, U1.5 (V+)

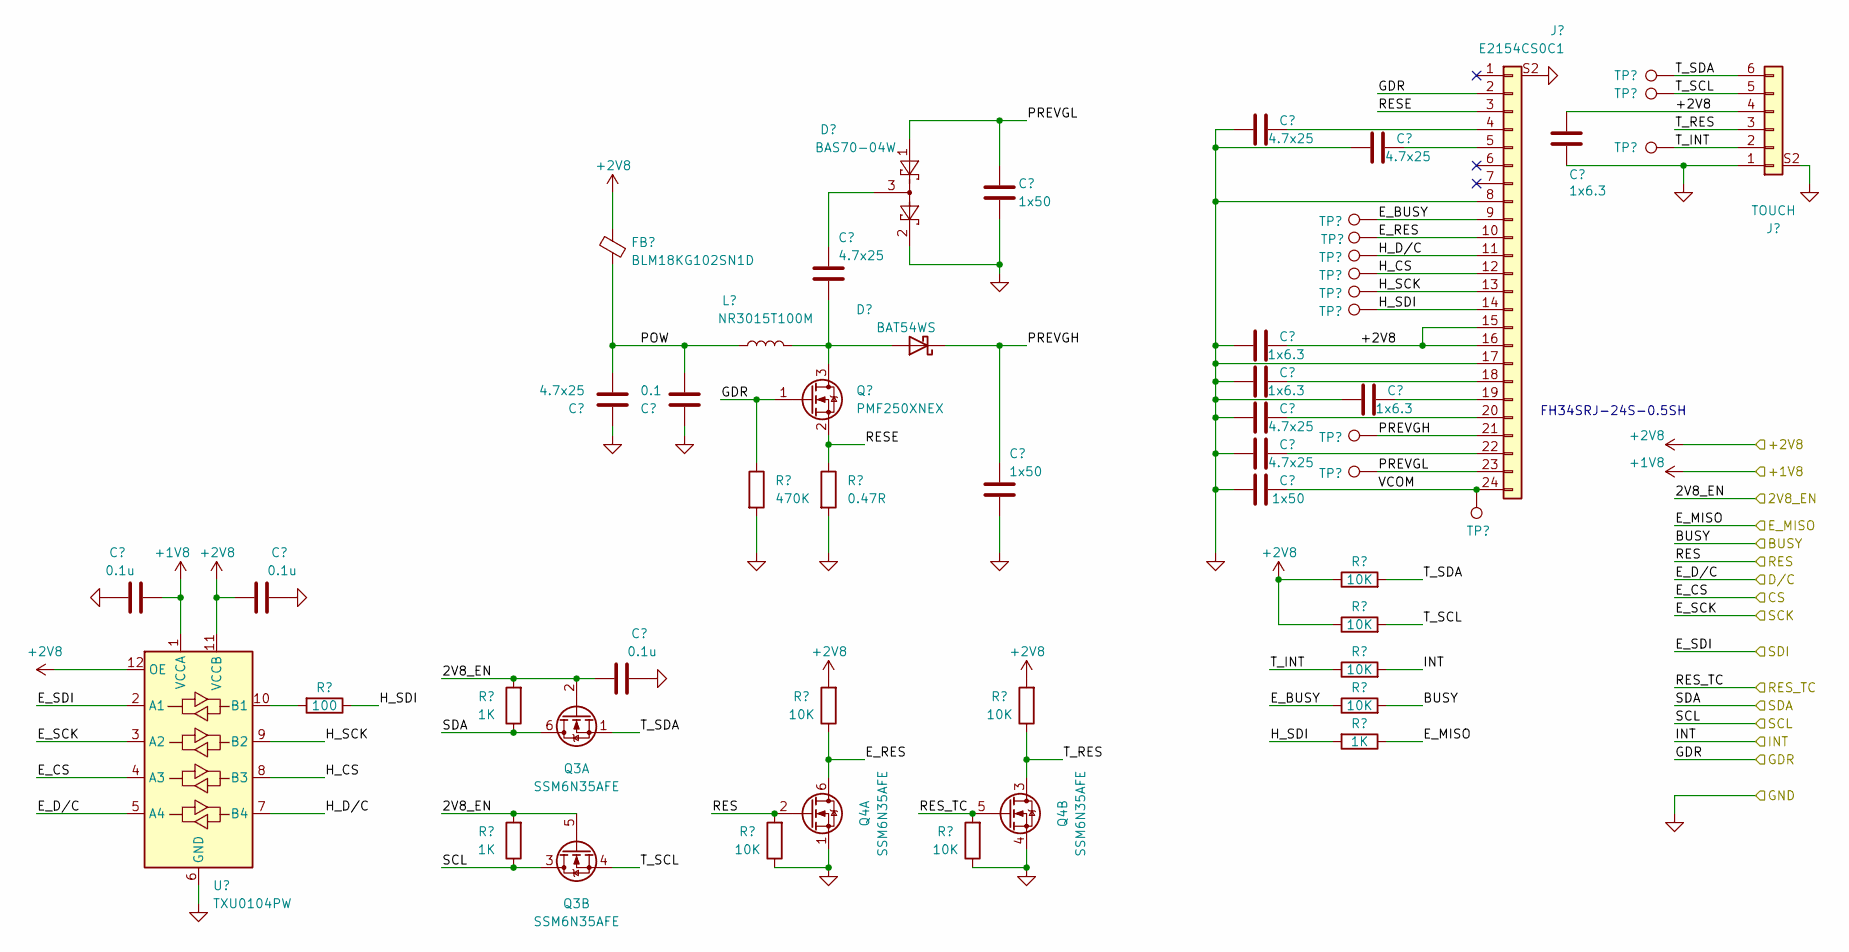
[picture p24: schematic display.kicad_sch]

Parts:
C41, C42, C46: 0.1u; C_0402_1005Metric
C43, C45, C49, C52, C53, C56: 4.7x25; C_0603_1608Metric
C44: 0.1; C_0402_1005Metric
C47, C48, C54: 1x50; C_0402_1005Metric
C50, C51, C55, C57: 1x6.3; C_0402_1005Metric
D9: BAS70-04W; SOT-323_SC-70
D10: BAT54WS; D_SOD-323F
FB4: BLM18KG102SN1D; L_0603_1608Metric
J4: E2154CS0C1; GDEY027T91-T01_bended
J5: TOUCH; HRS_FH34SRJ-6S-0.5SH(50)
L3: NR3015T100M; L_Wuerth_MAPI-3015
Q2: PMF250XNEX; SOT-323_SC-70
Q3, Q4: SSM6N35AFE; SOT-563
R6, R23, R24, R25, R26, R27, R28, R29: 10K; R_0402_1005Metric
R19: 470K; R_0402_1005Metric
R20, R21, R34: 1K; R_0402_1005Metric
R22: 0.47R; R_0603_1608Metric
R33: 100; R_0402_1005Metric
TP7, TP8, TP9, TP10, TP11, TP12, TP13, TP14, TP15, TP23, TP24, TP25: TestPoint; TestPoint_Pad_D1.0mm
U7: TXU0104PW; Texas_R-PUQFN-N12

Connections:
+1V8: C41.2, U7.1 (VCCA); also elsewhere on the board
+2V8: C42.1, C50.2, C57.1, FB4.2, J4.15, J4.16, J5.4, R24.2, R25.1, R26.1, R29.2, U7.11 (VCCB), U7.12 (OE); also elsewhere on the board
/Display/2V8_EN: C46.1, Q3.2 (G), Q3.5 (G), R20.2, R21.2; also elsewhere on the board
/Display/BUSY: R27.2; also elsewhere on the board
/Display/E_BUSY: J4.9, R27.1, TP7.1
/Display/E_CS: U7.4 (A3); also elsewhere on the board
/Display/E_D/C: U7.5 (A4); also elsewhere on the board
/Display/E_MISO: R34.1; also elsewhere on the board
/Display/E_RES: J4.10, Q4.6 (D), R24.1, TP8.1
/Display/E_SCK: U7.3 (A2); also elsewhere on the board
/Display/E_SDI: U7.2 (A1); also elsewhere on the board
/Display/H_CS: J4.12, TP10.1, U7.8 (B3)
/Display/H_D/C: J4.11, TP9.1, U7.7 (B4)
/Display/H_SCK: J4.13, TP11.1, U7.9 (B2)
/Display/H_SDI: J4.14, R33.1, R34.2, TP12.1
/Display/INT: R28.2; also elsewhere on the board
/Display/POW: C43.2, C44.1, FB4.1, L3.1
/Display/PREVGH: C48.1, D10.1 (K), J4.21, TP13.1
/Display/PREVGL: C47.1, D9.1, J4.23, TP14.1
/Display/RES: Q4.2 (G), R23.2; also elsewhere on the board
/Display/RES_TC: Q4.5 (G), R6.2; also elsewhere on the board
/Display/SCL: Q3.3 (D), R21.1; also elsewhere on the board
/Display/SDA: Q3.6 (D), R20.1; also elsewhere on the board
/Display/T_INT: J5.2, R28.1, TP25.1
/Display/T_RES: J5.3, Q4.3 (D), R29.1
/Display/T_SCL: J5.5, Q3.4 (S), R26.2, TP24.1
/Display/T_SDA: J5.6, Q3.1 (S), R25.2, TP23.1
/Display/VCOM: C54.2, J4.24, TP15.1
GND: C41.1, C42.2, C43.1, C44.2, C46.2, C47.2, C48.2, C49.1, C50.1, C51.1, C52.1, C53.1, C54.1, C55.1, C56.1, C57.2, D9.2, J4.8, J4.17, J4.S2 (S), J5.1, J5.S2 (S), Q4.1 (S), Q4.4 (S), R6.1, R19.2, R22.2, R23.1, U7.6 (GND); also elsewhere on the board
unnamed: C45.1, D9.3
unnamed: C49.2, J4.4
unnamed: C56.2, J4.5
unnamed: C51.2, J4.18
unnamed: C55.2, J4.19
unnamed: C52.2, J4.20
unnamed: C53.2, J4.22
unnamed: R33.2, U7.10 (B1)

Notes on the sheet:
FH34SRJ-24S-0.5SH

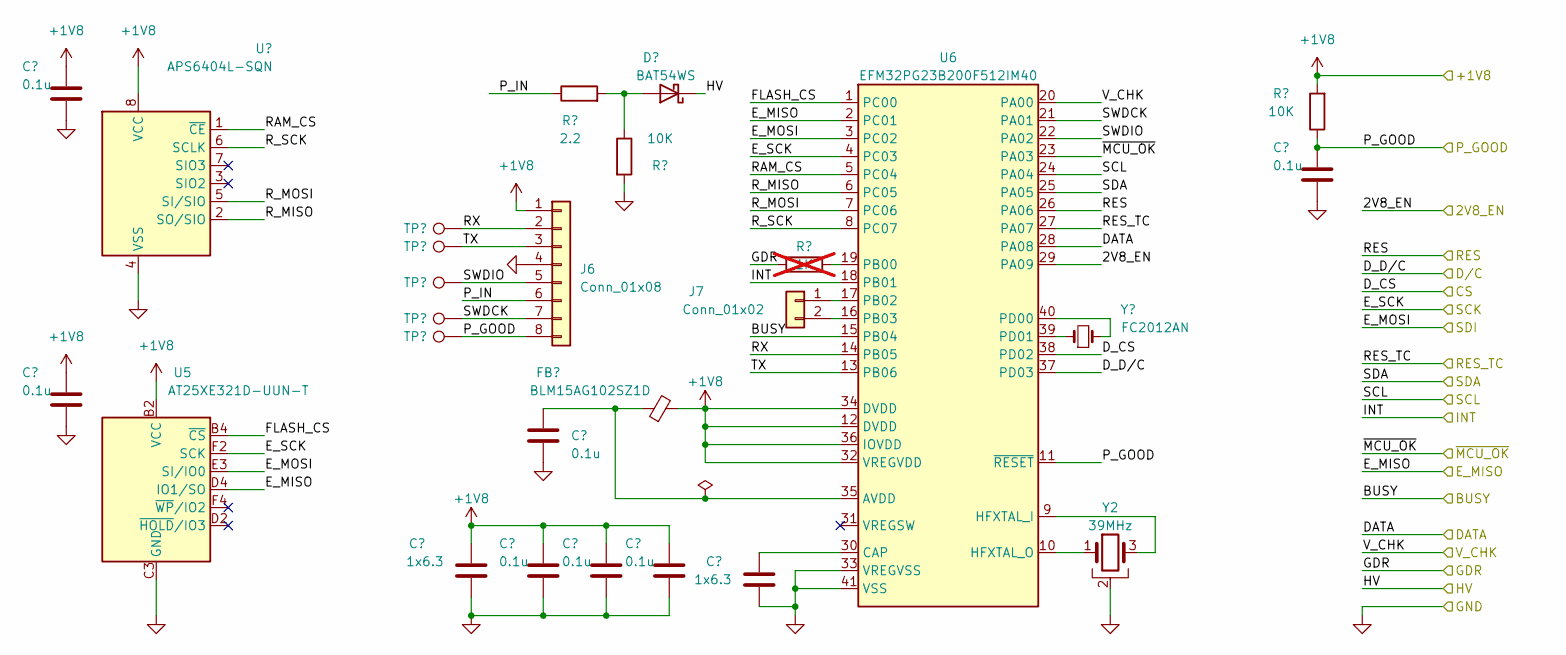
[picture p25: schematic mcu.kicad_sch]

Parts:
C32, C33, C35, C36, C37, C38, C40: 0.1u; C_0402_1005Metric
C34, C39: 1x6.3; C_0402_1005Metric
D7: BAT54WS; D_SOD-323F
FB3: BLM15AG102SZ1D; L_0402_1005Metric
J6: Conn_01x08; PinHeader_1x08_P1.27mm_Vertical
J7: Conn_01x02; PinHeader_1x02_P1.27mm_Vertical
R17, R18: 10K; R_0402_1005Metric
R32: 2.2; R_0603_1608Metric
R35: 1K; R_0402_1005Metric; not fitted
TP16, TP17, TP18, TP19, TP20: TestPoint; TestPoint_Pad_D1.0mm
U4: APS6404L-SQN; SON-8-1EP_3x2mm_P0.5mm_EP1.4x1.6mm
U5: AT25XE321D-UUN-T; WLCSP 12-ball 3 x 2 x 3 Array
U6: EFM32PG23B200F512IM40; QFN-40_EP_5x5_Pitch0.4mm
Y1: FC2012AN; Crystal_SMD_2012-2Pin_2.0x1.2mm
Y2: 39MHz; Crystal_SMD_2016-4Pin_2.0x1.6mm

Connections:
+1V8: C32.1, C33.1, C34.2, C35.1, C36.1, C38.1, FB3.2, J6.1, R18.2, U4.8 (VCC), U5.B2 (VCC), U6.12 (DVDD), U6.32 (VREGVDD), U6.34 (DVDD), U6.36 (IOVDD); also elsewhere on the board
/Display/2V8_EN: U6.29 (PA09); also elsewhere on the board
/Display/BUSY: U6.15 (PB04); also elsewhere on the board
/Display/E_CS: U6.38 (PD02); also elsewhere on the board
/Display/E_D/C: U6.37 (PD03); also elsewhere on the board
/Display/E_MISO: U5.D4 (IO1/SO), U6.2 (PC01); also elsewhere on the board
/Display/E_SCK: U5.F2 (SCK), U6.4 (PC03); also elsewhere on the board
/Display/E_SDI: U5.E3 (SI/IO0), U6.3 (PC02); also elsewhere on the board
/Display/INT: U6.18 (PB01); also elsewhere on the board
/Display/RES: U6.26 (PA06); also elsewhere on the board
/Display/RES_TC: U6.27 (PA07); also elsewhere on the board
/Display/SCL: U6.24 (PA04); also elsewhere on the board
/Display/SDA: U6.25 (PA05); also elsewhere on the board
/MCU/DATA: U6.28 (PA08); also elsewhere on the board
/MCU/FLASH_CS: U5.B4 (~CS), U6.1 (PC00)
/MCU/P_GOOD: C40.1, J6.8, R18.1, TP20.1, U6.11 (~RESET); also elsewhere on the board
/MCU/P_IN: J6.6, R32.1
/MCU/RAM_CS: U4.1 (~CE), U6.5 (PC04)
/MCU/RX: J6.2, TP16.1, U6.14 (PB05)
/MCU/R_MISO: U4.2 (SO/SIO), U6.6 (PC05)
/MCU/R_MOSI: U4.5 (SI/SIO), U6.7 (PC06)
/MCU/R_SCK: U4.6 (SCLK), U6.8 (PC07)
/MCU/SWDCK: J6.7, TP19.1, U6.21 (PA01)
/MCU/SWDIO: J6.5, TP18.1, U6.22 (PA02)
/MCU/TX: J6.3, TP17.1, U6.13 (PB06)
/MCU/V_CHK: U6.20 (PA00); also elsewhere on the board
/MCU/~MCU_OK: U6.23 (PA03); also elsewhere on the board
GND: C32.2, C33.2, C34.1, C35.2, C36.2, C37.2, C38.2, C39.1, C40.2, J6.4, R17.2, U4.4 (VSS), U5.C3 (GND), U6.33 (VREGVSS), U6.41 (VSS), Y2.2; also elsewhere on the board
unnamed: D7.2 (A), R17.1, R32.2
unnamed: J7.1, U6.17 (PB02)
unnamed: J7.2, U6.16 (PB03)
unnamed: C37.1, FB3.1, U6.35 (AVDD)
unnamed: C39.2, U6.30 (CAP)
unnamed: U6.9 (HFXTAL_I), Y2.3
unnamed: U6.10 (HFXTAL_O), Y2.1
unnamed: R35.2, U6.19 (PB00)
unnamed: U6.40 (PD00), Y1.2
unnamed: U6.39 (PD01), Y1.1

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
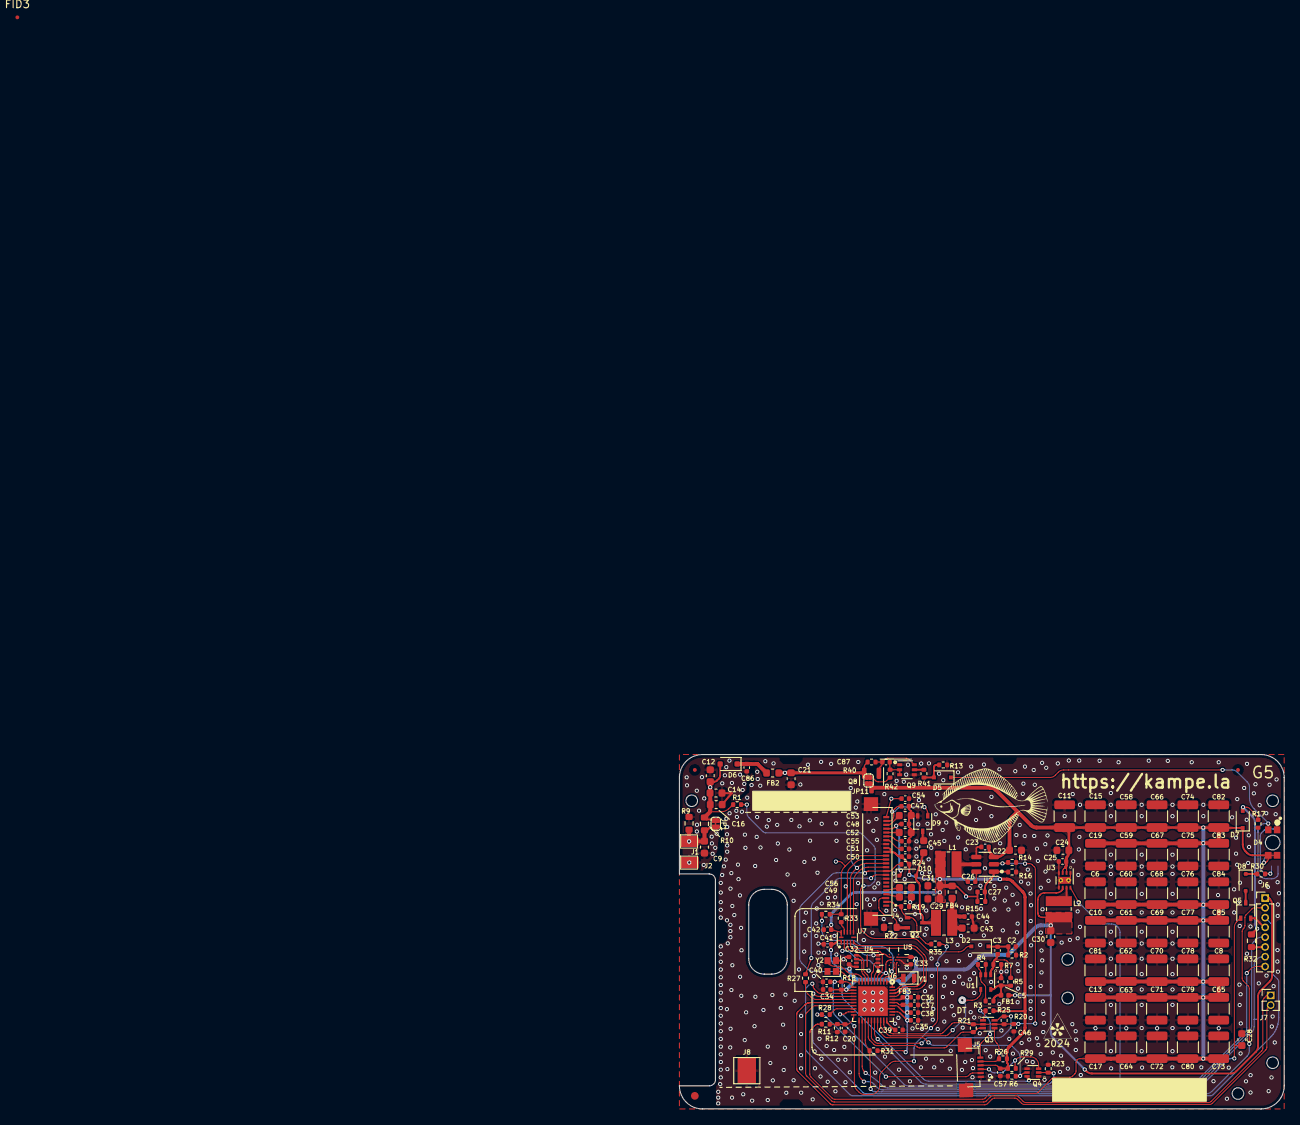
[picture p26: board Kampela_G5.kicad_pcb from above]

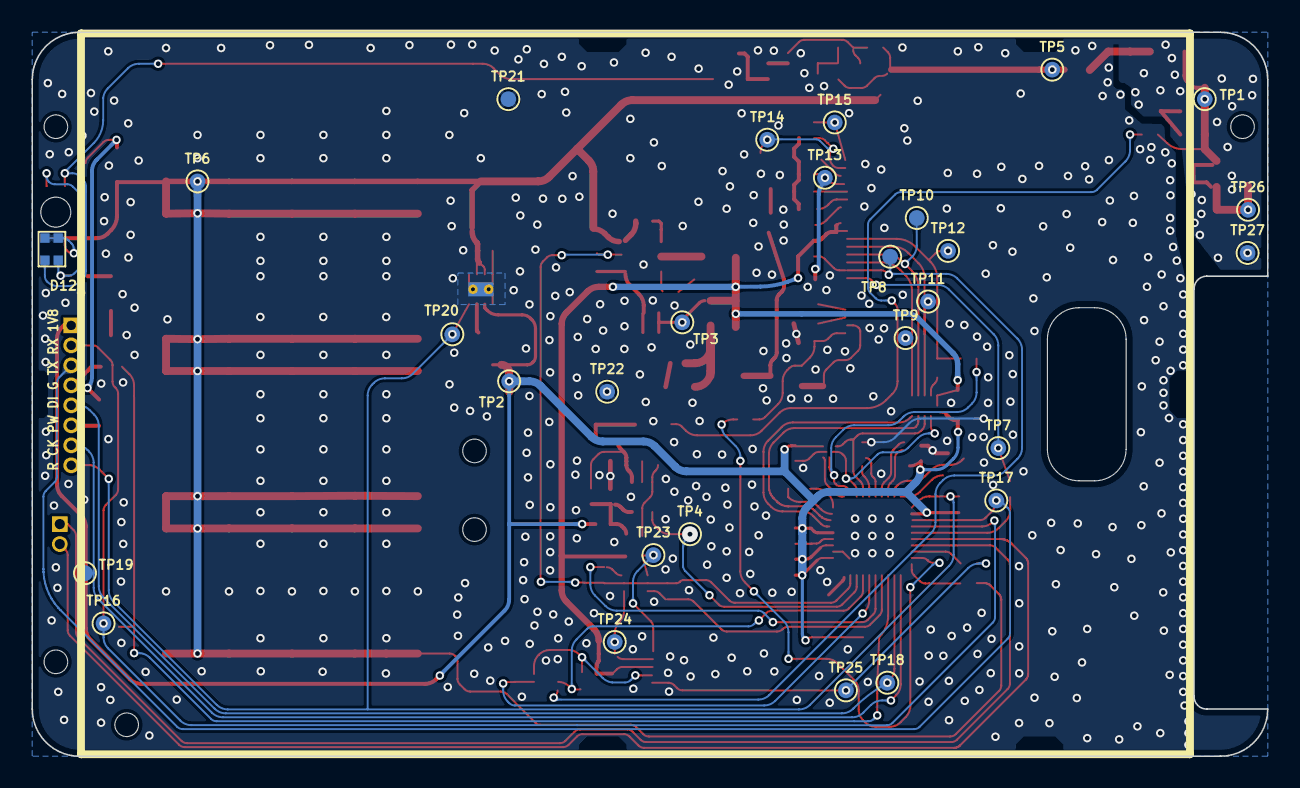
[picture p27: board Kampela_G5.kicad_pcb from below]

Board: 2 copper layers, 78.5 x 46.0 mm, 194 parts (28 on the bottom side), 86 nets.

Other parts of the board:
Q8: NTR5105PT1G; SOT-23

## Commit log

2023-06-19 major: port system crate to E hardware edition (#53)
    * feat: E1 schematics
    * chore: backup C1 kampela-system version
    * feat: change pin locations
    * feat: UI works on E
    [Kampela.kicad_sch, Kampela_E1.kicad_pcb, Kampela_E1.kicad_sch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]
2023-09-14 G2 revision
    G2 revision = Kampela development kit
    Features:
    - electronics is more stable and reliable
    - better power harvesting efficiency
    - fixed a touchscreen instability with powerful NFC transmitters
    - mechanical layout improved for low-volume productions for a devkit batch
    - NFC coil placed closer to the phone antenna. The coil parameters are optimized based on a mathematical model of the NFS harvester circuit.
    [Coil8.kicad_pcb, Coil8.kicad_sch, Kampela_E1.kicad_pcb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]
2024-11-01 G5 revision
    [Kampela_G2-B_Cu.gbr, Kampela_G2-B_Mask.gbr, Kampela_G2-B_Silkscreen.gbr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]
2024-11-26 Add G5 revision enclosure
    [Kampela_Enclosure_G2.STEP, Prog2Bot.STEP, TAG5.STEP]
2024-11-26 fix: restore kampela enclosure
    [Kampela_Enclosure_G2.STEP]
2024-11-28 Add files via upload
    fix: restore the kampela enclosure file
    [Kampela_Enclosure.STEP]
2025-05-06 Adding enclosure manufacturing form files.
    [$$FCPK_196x196_PK_PK01_22_1_1730_PK03_17_1_1730_PK03_17_1_1730_NO.sldasm, FCPK_196x196_PK_PK01_22_1_1730_PK03_17_1_1730_PK03_17_1_1730_NO.sldasm, PK 01-196x196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]
2025-05-06 Add "New Layout" enclosure files
    [Assembly1.SLDASM, Board.SLDPRT, Body.SLDPRT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]
2025-05-29 Add H1 revision (dual head)
    [Kampela_H1-B_Cu.gbr, Kampela_H1-B_Mask.gbr, Kampela_H1-B_Silkscreen.gbr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]
